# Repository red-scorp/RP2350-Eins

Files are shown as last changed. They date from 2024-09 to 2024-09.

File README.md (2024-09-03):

```
  _____  _____ ___  ____  _____  ___         ______ _____ _   _  _____ 
 |  __ \|  __ \__ \|___ \| ____|/ _ \       |  ____|_   _| \ | |/ ____|
 | |__) | |__) | ) | __) | |__ | | | |______| |__    | | |  \| | (___  
 |  _  /|  ___/ / / |__ <|___ \| | | |______|  __|   | | | . ` |\___ \ 
 | | \ \| |    / /_ ___) |___) | |_| |      | |____ _| |_| |\  |____) |
 |_|  \_\_|   |____|____/|____/ \___/       |______|_____|_| \_|_____/ 
```

# RP2350-Eins Project

The **RP2350-Eins** project aims to create a replacement for the Arduino UNO R3 or Arduino M0 using the RP2350 MCU.
This project was born as a continuation my previous project, [RP2040-Eins](https://github.com/red-scorp/RP2040-Eins), which was based on the Raspberry Pi RP2040 MCU.

## RP2350-Eins Board

The **RP2350-Eins** board is a 4-layer design intended to accommodate the popular Raspberry Pi RP2350 MCU within the standard Arduino UNO R3 footprint.

This board is crafted in Germany, and its name, "RP2350-Eins", incorporates the German word "Eins" (pronounced as "eye-ns"), which translates to "one". This name choice reflects the use of the same form-factor as the Arduino "Uno", which means "one" in Italian.

Preview:

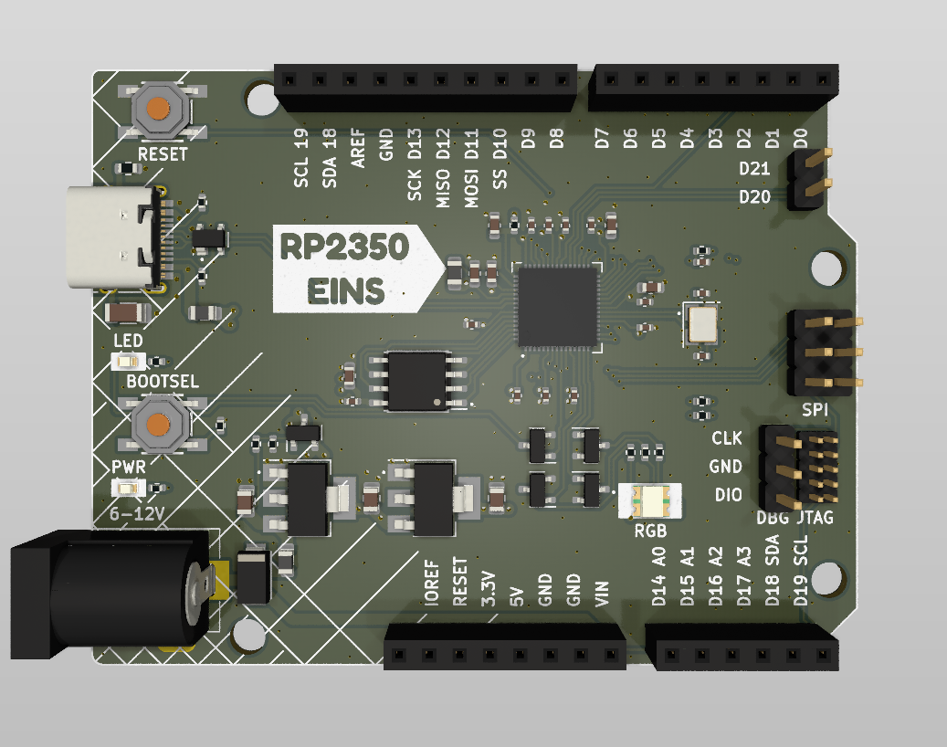
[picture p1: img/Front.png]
RP2350-Eins Front preview

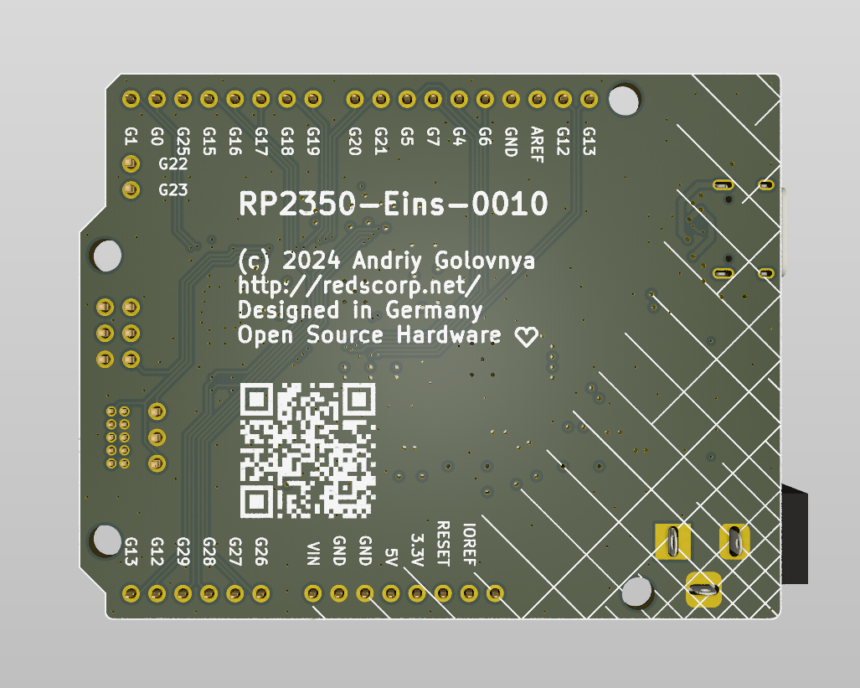
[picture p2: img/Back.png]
RP2350-Eins Back preview

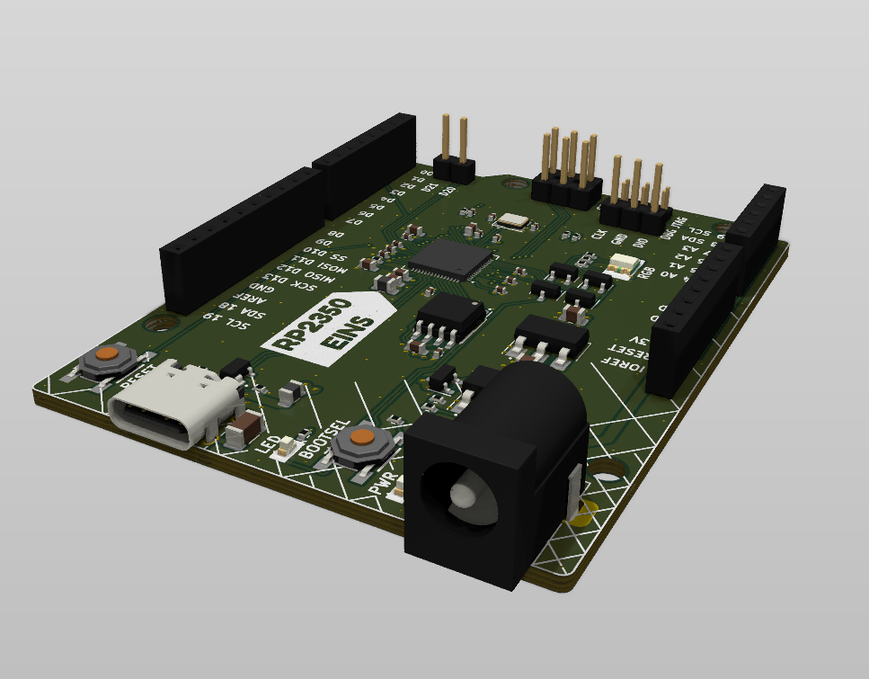
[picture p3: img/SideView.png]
RP2350-Eins Side View preview


You can view the [Schematics in PDF format](doc/RP2350-Eins.pdf) for detailed information.

STEP 3D file is available [with pins](doc/RP2350-Eins.step).

Features:

- Arduino UNO compatible pinout
- Partially compatible with Arduino Nano RP2350 Connect pinout
- Dual-core Cortex-M0+ Raspberry Pi RP2350
- 21 GPIO pins, including 4 analog inputs
- USB Type-C connector
- JTAG and DBG debugging connectors
- LDO-based 5V and 3.3V power supply with a maximum 12V input
- Supports both SOIC and WSON 16MB flash packages
- Includes power, user and RGB LEDs

CAM files, as well as the BOM and CPL files for JLCPCB, are available.

### Board Pinout

Following pinout is used for the board:

| Board Pin | RP2350 Pin | Function | Notes |
| --- | --- | --- | ----- |
| D0 | GPIO1 | UART0 TX | |
| D1 | GPIO0 | UART0 RX | |
| D2 | GPIO25 | | |
| D3 | GPIO15 | | |
| D4 | GPIO16 | | |
| D5 | GPIO17 | | |
| D6 | GPIO18 | | |
| D7 | GPIO19 | | |
| D8 | GPIO20 | | |
| D9 | GPIO21 | | |
| D10 | GPIO5 | SS | |
| D11 | GPIO7 | MOSI | |
| D12 | GPIO4 | MISO | |
| D13 | GPIO6 | SCK | LED |
| D14 A0 | GPIO26 | | |
| D15 A1 | GPIO27 | | |
| D16 A2 | GPIO28 | | |
| D17 A3 | GPIO29 | | |
| D18 | GPIO12 | SDA | |
| D19 | GPIO13 | SCL | |
| D20 | GPIO22 | | |
| D21 | GPIO23 | | |
| LED_R | GPIO9 | | |
| LED_G | GPIO10 | | |
| LED_B | GPIO11 | | |

## Version History

This board exists in a single LDO-based flavor. If you want to use a Buck-based version of this board, please contact me directly.

Each version of the board listed below is tagged in the repository. You can use the tag to checkout the repository to the specific version.

### v1.0b1 - xx.xx.2024

v1.0b1 board preview

Initial release for testing purposes.

## Links

- [Raspberry Pi RP2350 information page](https://www.raspberrypi.com/documentation/microcontrollers/silicon.html#rp2350).
- [Arduino UNO R3 information page](https://docs.arduino.cc/retired/boards/arduino-uno-rev3-with-long-pins).
- [Arduino SDK for RP2040/RP2350 board](https://github.com/earlephilhower/arduino-pico).

## How to Help

Your contributions as code, resources, or finances are welcome! Please contact me directly via email at andriy.golovnya@gmail.com or through my [GitHub profile](https://github.com/red-scorp).

If you'd like to make a financial contribution, you can donate via [PayPal](http://paypal.me/redscorp) or [Ko-Fi](http://ko-fi.com/redscorp). Your support is greatly appreciated.

Thanks in advance!

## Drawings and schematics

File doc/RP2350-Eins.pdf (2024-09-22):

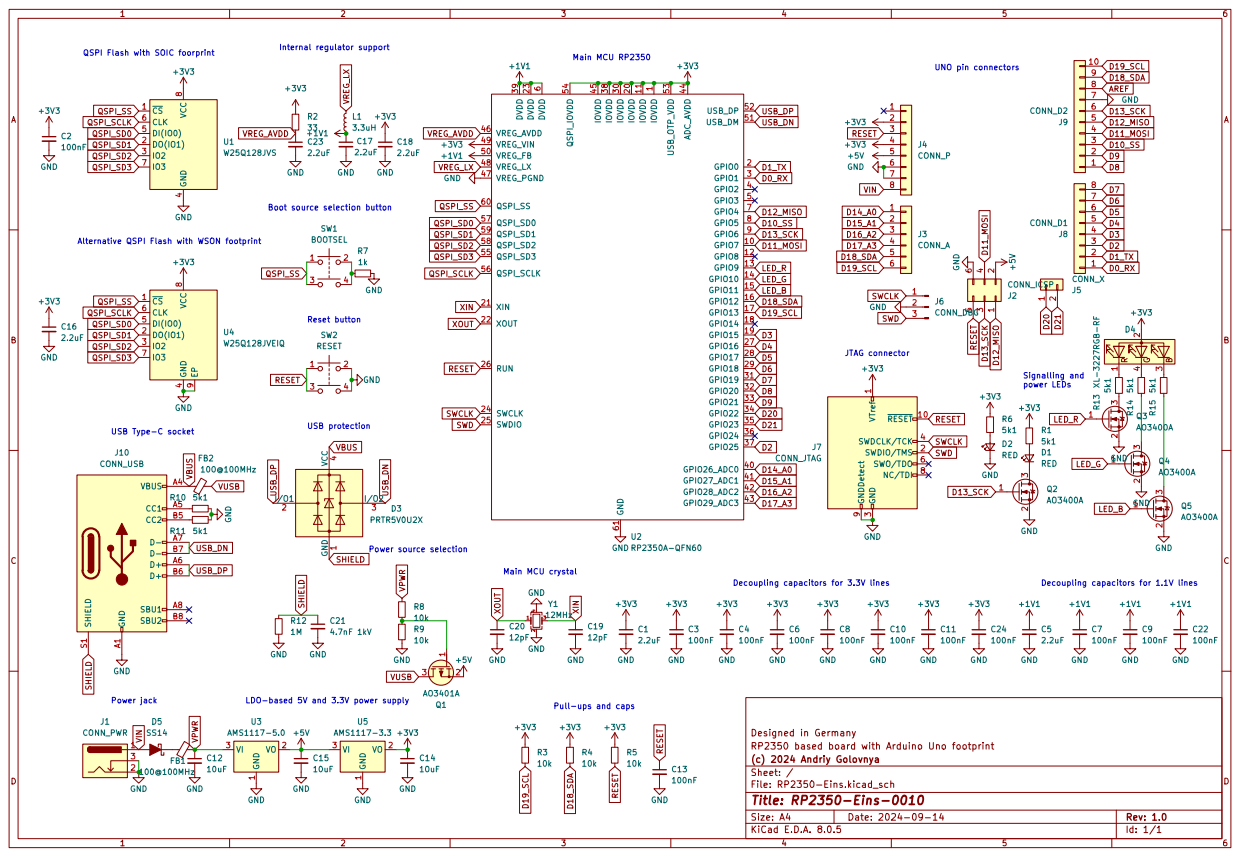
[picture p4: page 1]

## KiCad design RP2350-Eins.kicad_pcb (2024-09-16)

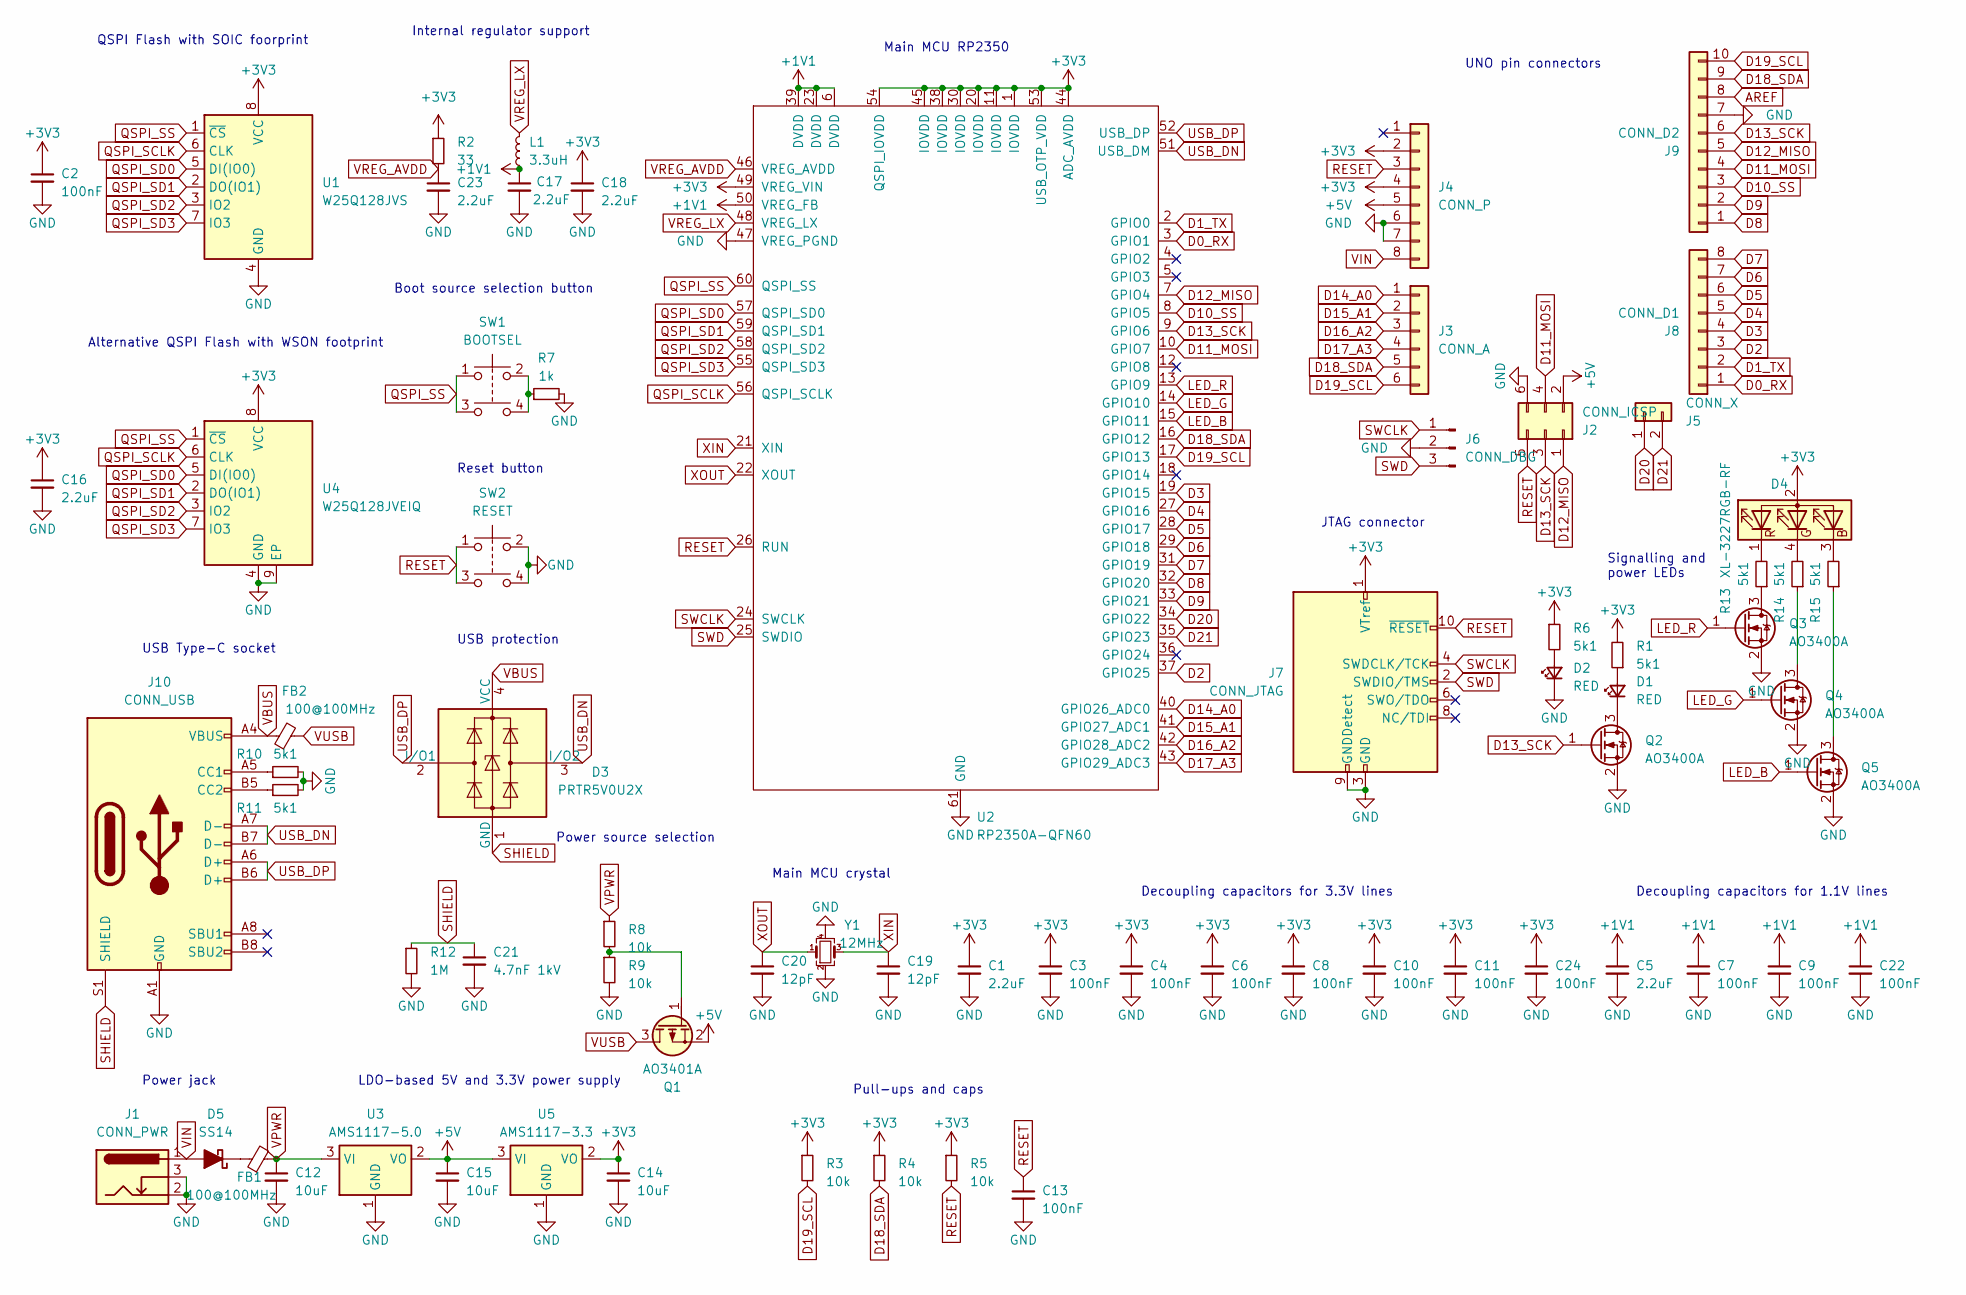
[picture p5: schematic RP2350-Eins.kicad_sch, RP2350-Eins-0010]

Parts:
C1, C5, C16, C17, C18, C23: 2.2uF; C_0603_1608Metric
C2, C3, C4, C6, C7, C8, C9, C10, C11, C13, C22, C24: 100nF; C_0402_1005Metric
C12, C14, C15: 10uF; C_0805_2012Metric
C19, C20: 12pF; C_0402_1005Metric
C21: 4.7nF 1kV; C_1206_3216Metric
D1, D2: RED; LED_0603_1608Metric
D3: PRTR5V0U2X; SOT-143
D4: XL-3227RGB-RF; LED_RGB_1210
D5: SS14; D_DO-214AC_SMA
FB1, FB2: 100@100MHz; L_0805_2012Metric
J1: CONN_PWR; BarrelJack_Horizontal
J2: CONN_ICSP; PinHeader_2x03_P2.54mm_Vertical
J3: CONN_A; PinSocket_1x06_P2.54mm_Vertical
J4: CONN_P; PinSocket_1x08_P2.54mm_Vertical
J5: CONN_X; PinHeader_1x02_P2.54mm_Vertical
J6: CONN_DBG; PinHeader_1x03_P2.54mm_Vertical
J7: CONN_JTAG; PinHeader_2x05_P1.27mm_Vertical
J8: CONN_D1; PinSocket_1x08_P2.54mm_Vertical
J9: CONN_D2; PinSocket_1x10_P2.54mm_Vertical
J10: CONN_USB; USB_C_Receptacle_HRO_TYPE-C-31-M-12
L1: 3.3uH; L_0805_2012Metric
Q1: AO3401A; SOT-23
Q2, Q3, Q4, Q5: AO3400A; SOT-23
R1, R6, R10, R11, R13, R14, R15: 5k1; R_0402_1005Metric
R2: 33; R_0402_1005Metric
R3, R4, R5, R8, R9: 10k; R_0402_1005Metric
R7: 1k; R_0402_1005Metric
R12: 1M; R_0603_1608Metric
SW1: BOOTSEL; Button_Tact_Sqkg
SW2: RESET; Button_Tact_Sqkg
U1: W25Q128JVS; SOIC-8_5.23x5.23mm_P1.27mm
U2: RP2350A-QFN60; RP2350A_QFN-60_EP_7.75x7.75_Pitch0.4mm
U3: AMS1117-5.0; SOT-223-3_TabPin2
U4: W25Q128JVEIQ; WSON-8-1EP_6x5mm_P1.27mm_EP3.4x4.3mm
U5: AMS1117-3.3; SOT-223-3_TabPin2
Y1: 12MHz; Crystal_SMD_3225-4Pin_3.2x2.5mm

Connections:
+1V1: C5.1, C7.1, C9.1, C17.1, C22.1, L1.1, U2.6 (DVDD), U2.23 (DVDD), U2.39 (DVDD), U2.50 (VREG_FB)
+3V3: C1.1, C2.1, C3.1, C4.1, C6.1, C8.1, C10.1, C11.1, C14.1, C16.1, C18.1, C24.1, D4.2 (A), J4.2, J4.4, J7.1 (VTref), R1.2, R2.1, R3.1, R4.1, R5.1, R6.1, U1.8 (VCC), U2.1 (IOVDD), U2.11 (IOVDD), U2.20 (IOVDD), U2.30 (IOVDD), U2.38 (IOVDD), U2.44 (ADC_AVDD), U2.45 (IOVDD), U2.49 (VREG_VIN), U2.53 (USB_OTP_VDD), U2.54 (QSPI_IOVDD), U4.8 (VCC), U5.2 (VO)
+5V: C15.1, J2.2, J4.5, Q1.2 (S), U3.2 (VO), U5.3 (VI)
AREF: J9.8
D0_RX: J8.1, U2.3 (GPIO1)
D1_TX: J8.2, U2.2 (GPIO0)
D2: J8.3, U2.37 (GPIO25)
D3: J8.4, U2.19 (GPIO15)
D4: J8.5, U2.27 (GPIO16)
D5: J8.6, U2.28 (GPIO17)
D6: J8.7, U2.29 (GPIO18)
D7: J8.8, U2.31 (GPIO19)
D8: J9.1, U2.32 (GPIO20)
D9: J9.2, U2.33 (GPIO21)
D10_SS: J9.3, U2.8 (GPIO5)
D11_MOSI: J2.4, J9.4, U2.10 (GPIO7)
D12_MISO: J2.1, J9.5, U2.7 (GPIO4)
D13_SCK: J2.3, J9.6, Q2.1 (G), U2.9 (GPIO6)
D14_A0: J3.1, U2.40 (GPIO26_ADC0)
D15_A1: J3.2, U2.41 (GPIO27_ADC1)
D16_A2: J3.3, U2.42 (GPIO28_ADC2)
D17_A3: J3.4, U2.43 (GPIO29_ADC3)
D18_SDA: J3.5, J9.9, R4.2, U2.16 (GPIO12)
D19_SCL: J3.6, J9.10, R3.2, U2.17 (GPIO13)
D20: J5.1, U2.34 (GPIO22)
D21: J5.2, U2.35 (GPIO23)
GND: C1.2, C2.2, C3.2, C4.2, C5.2, C6.2, C7.2, C8.2, C9.2, C10.2, C11.2, C12.2, C13.2, C14.2, C15.2, C16.2, C17.2, C18.2, C19.2, C20.2, C21.2, C22.2, C23.2, C24.2, D2.1 (K), J1.2, J1.3, J2.6, J4.6, J4.7, J6.2, J7.3 (GND), J7.5 (GND), J7.9 (GNDDetect), J9.7, J10.A1 (GND), J10.A12 (GND), J10.B1 (GND), J10.B12 (GND), Q2.2 (S), Q3.2 (S), Q4.2 (S), Q5.2 (S), R7.2, R9.2, R10.2, R11.2, R12.2, SW2.2, SW2.4, U1.4 (GND), U2.47 (VREG_PGND), U2.61 (GND), U3.1 (GND), U4.4 (GND), U4.9 (EP), U5.1 (GND), Y1.2, Y1.4
LED_B: Q5.1 (G), U2.15 (GPIO11)
LED_G: Q4.1 (G), U2.14 (GPIO10)
LED_R: Q3.1 (G), U2.13 (GPIO9)
unnamed: D1.2 (A), R1.1
unnamed: D1.1 (K), Q2.3 (D)
unnamed: D2.2 (A), R6.2
unnamed: D4.3 (BK), R15.2
unnamed: D4.4 (GK), R14.2
unnamed: D4.1 (RK), R13.2
unnamed: D5.1 (K), FB1.1
unnamed: J10.A5 (CC1), R10.1
unnamed: J10.B5 (CC2), R11.1
unnamed: Q1.1 (G), R8.2, R9.1
unnamed: Q3.3 (D), R13.1
unnamed: Q4.3 (D), R14.1
unnamed: Q5.3 (D), R15.1
unnamed: R7.1, SW1.2, SW1.4
QSPI_SCLK: U1.6 (CLK), U2.56 (QSPI_SCLK), U4.6 (CLK)
QSPI_SD0: U1.5 (DI(IO0)), U2.57 (QSPI_SD0), U4.5 (DI(IO0))
QSPI_SD1: U1.2 (DO(IO1)), U2.59 (QSPI_SD1), U4.2 (DO(IO1))
QSPI_SD2: U1.3 (IO2), U2.58 (QSPI_SD2), U4.3 (IO2)
QSPI_SD3: U1.7 (IO3), U2.55 (QSPI_SD3), U4.7 (IO3)
QSPI_SS: SW1.1, SW1.3, U1.1 (~CS), U2.60 (QSPI_SS), U4.1 (~CS)
RESET: C13.1, J2.5, J4.3, J7.10 (~RESET), R5.2, SW2.1, SW2.3, U2.26 (RUN)
SHIELD: C21.1, D3.1 (GND), J10.S1 (SHIELD), R12.1
SWCLK: J6.1, J7.4 (SWDCLK/TCK), U2.24 (SWCLK)
SWD: J6.3, J7.2 (SWDIO/TMS), U2.25 (SWDIO)
USB_DN: D3.3 (I/O2), J10.A7 (D-), J10.B7 (D-), U2.51 (USB_DM)
USB_DP: D3.2 (I/O1), J10.A6 (D+), J10.B6 (D+), U2.52 (USB_DP)
VBUS: D3.4 (VCC), FB2.1, J10.A4 (VBUS), J10.A9 (VBUS), J10.B4 (VBUS), J10.B9 (VBUS)
VIN: D5.2 (A), J1.1, J4.8
VPWR: C12.1, FB1.2, R8.1, U3.3 (VI)
VREG_AVDD: C23.1, R2.2, U2.46 (VREG_AVDD)
VREG_LX: L1.2, U2.48 (VREG_LX)
VUSB: FB2.2, Q1.3 (D)
XIN: C19.1, U2.21 (XIN), Y1.3
XOUT: C20.1, U2.22 (XOUT), Y1.1

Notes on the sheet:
USB protection
Alternative QSPI Flash with WSON footprint
UNO pin connectors
Main MCU RP2350
Power source selection
Power jack
Decoupling capacitors for 3.3V lines
Main MCU crystal
Internal regulator support
Decoupling capacitors for 1.1V lines
Pull-ups and caps
Signalling and power LEDs
JTAG connector
Reset button
USB Type-C socket
Boot source selection button
LDO-based 5V and 3.3V power supply
QSPI Flash with SOIC foorprint

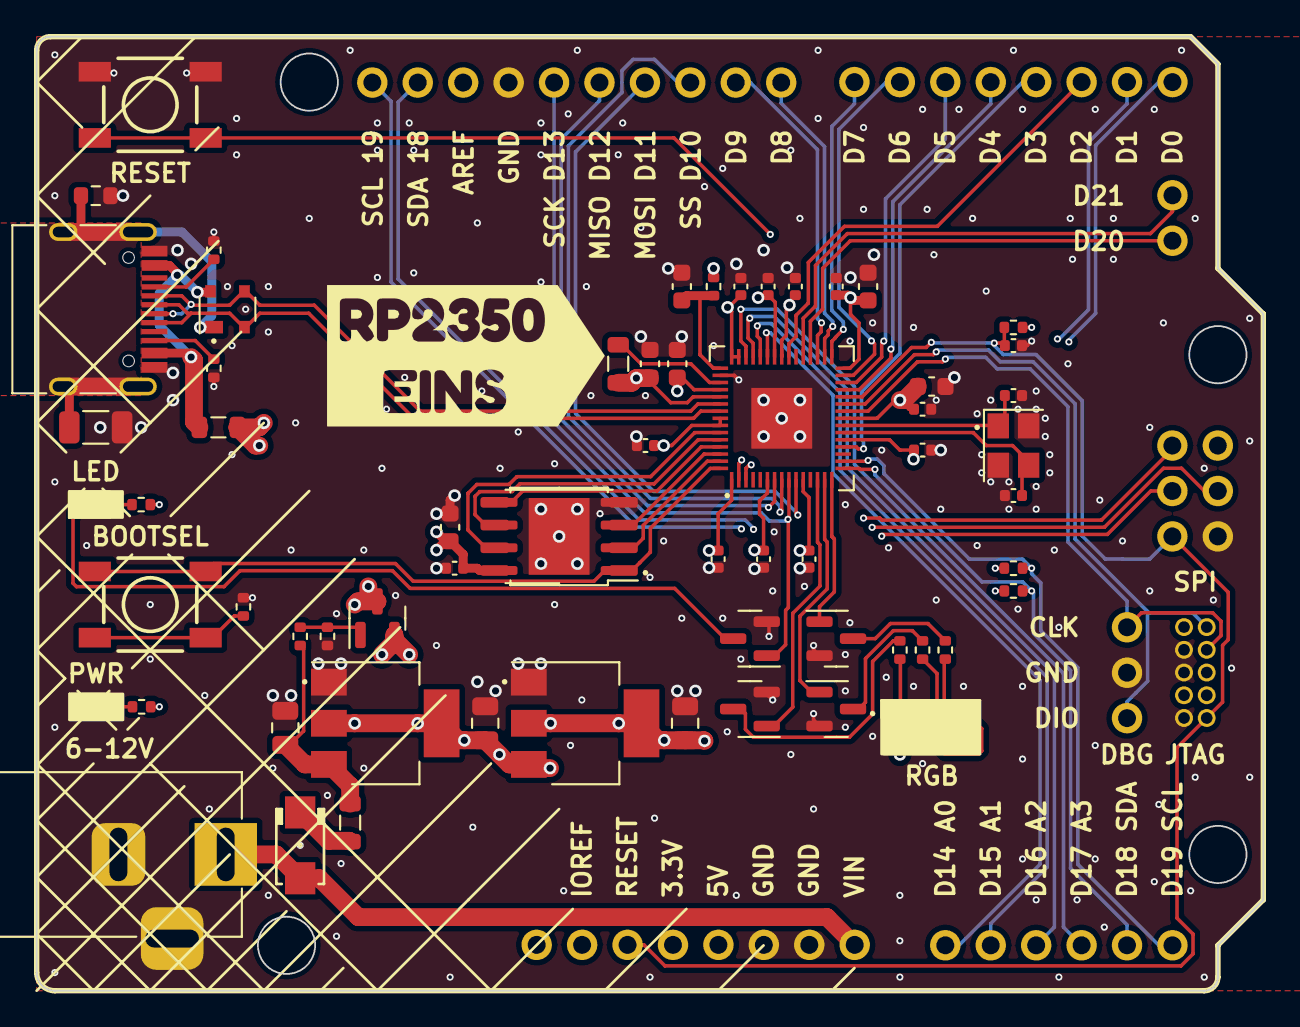
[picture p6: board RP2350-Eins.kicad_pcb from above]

Board: 4 copper layers, 68.6 x 53.3 mm, 72 parts (1 on the bottom side), 63 nets.

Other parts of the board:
G1: QR-CODE; LOGO
G2: G***; kibuzzard-66CA2205

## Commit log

2024-08-24 Added base for the board, based on previous design
    [RP2350-Eins.kicad_pcb, RP2350-Eins.kicad_sch]
2024-08-24 Added missing components. Routed the board.
    [RP2350-Eins.kicad_pcb, RP2350-Eins.kicad_sch]
2024-08-25 Added few vias. Moved staff around.
    [RP2350-Eins.kicad_pcb]
2024-08-25 Moved staff around.
    [RP2350-Eins.kicad_pcb, RP2350-Eins.kicad_sch]
2024-08-31 Use manual vias under RP2350 instead of from footprint
    [RP2350-Eins.kicad_pcb]
2024-09-22 Generated PDF schematics
2024-09-22 Added generic JLCPCB BOM
    [RP2350-Eins-20240922-JLCPCB-BOM.xlsx]
2024-09-22 Added generic JLCPCB CPL
    [RP2350-Eins-20240922-JLCPCB-CPL.xlsx]

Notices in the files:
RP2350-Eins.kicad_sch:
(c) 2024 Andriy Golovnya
